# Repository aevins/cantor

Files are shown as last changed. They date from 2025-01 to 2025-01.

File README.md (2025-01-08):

<!-- markdownlint-disable MD000 -->




# Cantor Keyboard

(Forked by [aevins](https://github.com/aevins) - see [upstream](https://github.com/diepala/cantor) for original by [diepala](https://github.com/diepala))

The Cantor keyboard is a 42 key diodeless split keyboard, designed with simplicity in mind. It is inspired on the popular [corne](https://github.com/foostan/crkbd), [ferris](https://github.com/pierrechevalier83/ferris) and [sweep](https://github.com/davidphilipbarr/Sweep) keyboards, aiming to provide a more ergonomic (stronger column stagger) corne-like layout with a simple, easy to assemble and cheap design.

Cantor Keyboard

There are two versions of the Cantor:

The **Cantor Classic** uses choc switches with choc spacing. Therefore, only MBK keycaps can be used.

The **Cantor MX** uses either choc V1, choc V2, or MX switches with the slightly larger MX spacing. Keycaps for MX stems can be used. (OEM/SA/XDM/Cherry, etc.) 

Cantor Keyboard

### Why diodeless?

A diodeless design reduces the keyboard assembly time, as the amount of components to solder is significantly reduced.
Moreover, soldering diodes can cause trouble during the keyboard build. Diodes need to be placed in the correct direction, if not, the keys won't work well!
Eliminating diodes will prevent many errors during the assembly process.

## Disclaimers

All the designs and files are provided "AS IS" without any warranty or support.

## Design philosophy

The Cantor is designed with the following goals:

- Comfort
- Powerful
- Low cost
- Simplicity
- Ease of build
- USB-C
- No diodes

The PCB is reversible to reduce manufacturing costs.

## Getting started

Would you like to build this keyboard? Then continue reading!

You can also buy a kit to build the Cantor keyboard from one of the **honorable sponsors**:



<br><br><br><br>
  
### Bill of Materials

To build the keyboard, you will need the following materials:
#### Cantor Classic:
- 2x PCB boards (both are equal since they are reversible)
- 2x STM32F401CC blackpill microcontrollers (they are cheap on aliexpress)
- Pins and sockets for the microcontrollers (blackpill needs 20 pin stripes)
- 42 Choc v1 switches
- 42 MBK keycaps
- Some little rubber feet/bumpers (recommended 6 mm of diameter)
- 2x TRRS jacks (PJ-320A)
- 1x TRRS cable
- 1x USB cable compatible with your computer and the blackpill

#### Cantor MX
- Same as the classic, but switches can be choc v1, choc v2, MX 5 pin, or MX 3pin, and the compatible keycaps for chosen switches. MX 5 pin are preferable to 3 pin because they have more points of contact with the PCB.

- Cantor MX has slots for optional 'Tenting pucks'. They can be [purchased](https://splitkb.com/products/tenting-puck) or [3d printed](https://www.printables.com/model/235433-tenting-puck-for-keyboard-tripod-mount).

### Order the PCB

Download the gerber file from releases, and submit it to your favorite PCB manufacturer. The keyboard designs have been tested with JLCPCB. More details on the ordering process can be found in the [PCB Ordering Guide](doc/pcb_ordering_guide.md).

Note: if you don't want a random tracking number to be printed in the PCB, make sure to select the option 'Remove Order Number' in JLCPCB.

### How to Build

To build the keyboard, you'll also need a soldering iron and some tin. Follow the [build guide](doc/build_guide.md).

### Firmware

The Cantor keyboard uses the QMK firmware, which already supports this keyboard.

To flash the firmware to the microcontroller connect the blackpill to your computer and set it to bootloader mode. To do this the first time:

1. Press and hold the BOOT0 button.
2. Press and release the NRST button.
3. Release the BOOT0 button.

The following times you want to flash the keyboard, it is much simpler thanks to bootmagic. Hold the top left key of the keyboard and plug the microcontroller. If flashing the right part, hold the top right key.

## Feedback

If you have built this keyboard, please fill [this form](https://forms.gle/nfJCsei5hyHbjaHn9) to provide feedback. This will help to improve the keyboard design in future revisions.

Also, you can open an issue reporting any problem or feature request.

> [!NOTE]
> Please see [original](https://github.com/diepala/cantor) for issues - this fork is for my personal development. I will try to address questions/issues if you have them which **specifically** relate to this fork.

## Support

The development of a keyboard takes time and money. If you like this keyboard a want to support the original creator for the work and to develop future revisions of the keyboard, consider donating:

PayPal: 
GitHub: [Here](https://github.com/sponsors/diepala)

### Honorable sponsors

Thank you very much to everyone contributing and/or sponsoring this project. Special thanks to the honorable sponsors:




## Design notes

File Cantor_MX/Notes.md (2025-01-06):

# Notes

## Purchased Items

### Amazon

#### Keycaps

Keycaps

- [Guffercty kred XDA Profile Keycaps 125 Retro PBT Key Cap Cover Set Dye Sublimation ANSI US Layout for Cherry Mx Switch Mechanical Keyboard (XDA/Ember)](https://www.amazon.com/gp/product/B09HX228WX/ref=ppx_yo_dt_b_asin_title_o00_s01?ie=UTF8&psc=1)

#### Controller

Controller

- [DORHEA 3Pcs STM32F401 Development Board V3.0 STM32F401CCU6 STM32F4 Learning Board 84Mhz Freq 64KB RAM 256KB ROM for Programming](https://www.amazon.com/gp/product/B09MLHYF89/ref=ppx_yo_dt_b_asin_title_o00_s00?ie=UTF8&psc=1)

#### TRRS Jacks

Jacks

- [uxcell 3.5 mm Audio Jack Connector PCB Mount Female Socket 4 Pin PJ-320A 20pcs](https://www.amazon.com/gp/product/B07KY862P6/ref=ppx_yo_dt_b_asin_title_o00_s00?ie=UTF8&psc=1)

#### Cables

Cable - USB-C

- [USB C to USB C Cable, Type C 60W Fast Charging Nylon Braided Cable [5FT, 2 Pack] for iPhone 16 15 Pro Plus Pro Max, Samsung Galaxy S24/S23, MacBook Pro, iPad Pro Air Mini USBC Charger Cord [Grey]](https://www.amazon.com/gp/product/B0DC5HQGSQ/ref=ppx_yo_dt_b_asin_title_o00_s00?ie=UTF8&psc=1)

Cable - TRRS

- [Kework 12 inch 2.5mm TRRS Audio Cable, 90 Degree Angle 2.5mm Male Jack to 90 Degree Angle 2.5mm Male Jack AUX Audio Cable, Gold Plated Pure Copper, 2 Pack](https://www.amazon.com/gp/product/B0CM5Q2PP8/ref=ppx_yo_dt_b_asin_title_o00_s02?ie=UTF8&psc=1)

#### Solder

Solder

- [MAIYUM 63-37 Tin Lead Rosin core solder wire for electrical soldering (0.6mm 100g)](https://www.amazon.com/gp/product/B076QD1W9X/ref=ppx_yo_dt_b_asin_title_o00_s02?ie=UTF8&psc=1)

### JLCPCB

Order [W202501042351396](https://jlcpcb.com/user-center/orderDetails/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)

### AliExpress

None - though keycaps, blackpill microcontroller, and Outemu switches are common and cheap here.

## Firmware

## Extras

### Case

Case

This case was [designed by JellyTitan on Printables](https://www.printables.com/model/707238-cantor-mx-case) and seems a good fit for this board.

## Ideas

- Make it wireless
- Convert TRRS to USB-C
- Use sockets for hotswappable controller
- Modify to accept MX Hotswaps
- Read [article](https://github.com/joric/nrfmicro/wiki/Sockets) on sockets

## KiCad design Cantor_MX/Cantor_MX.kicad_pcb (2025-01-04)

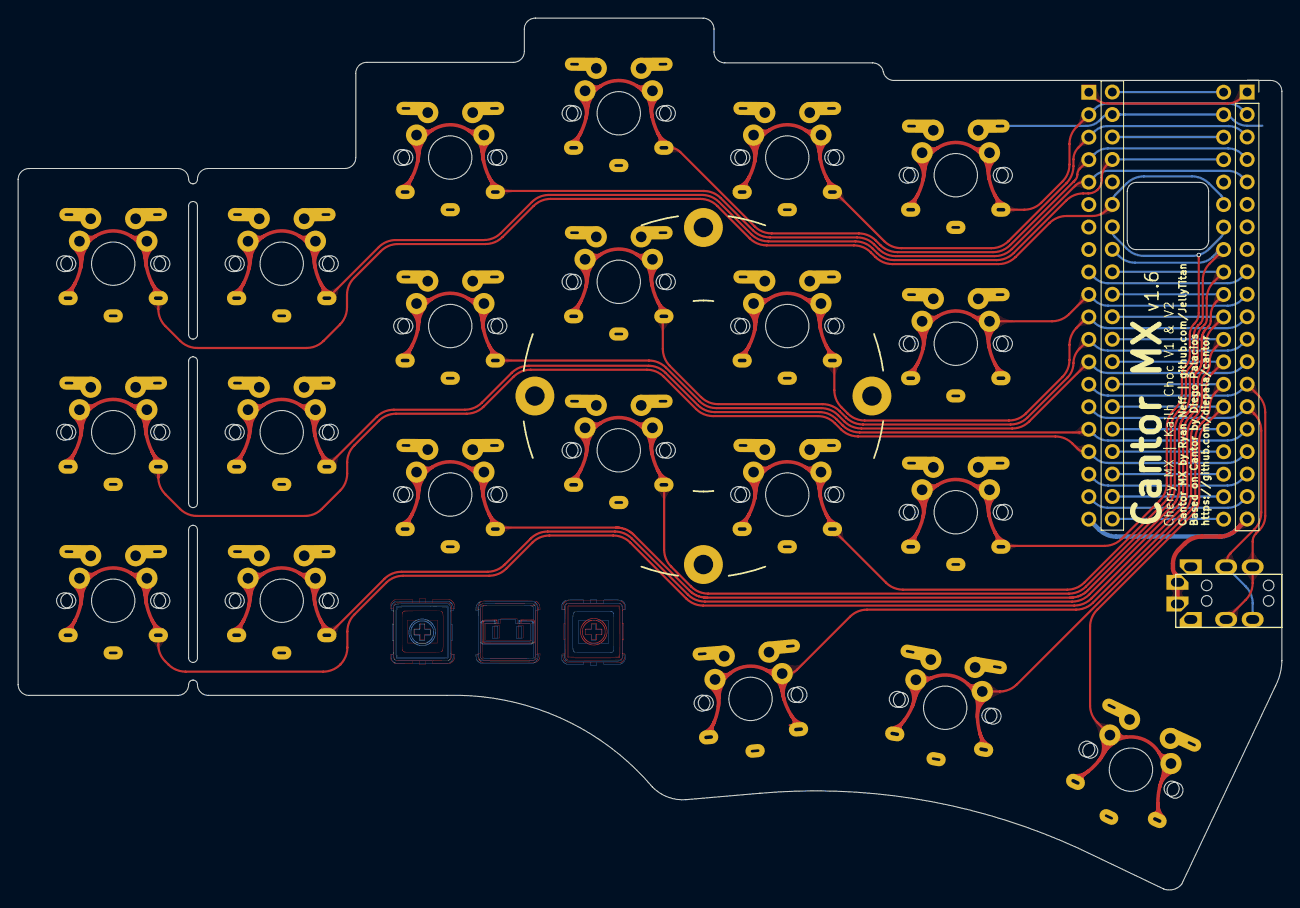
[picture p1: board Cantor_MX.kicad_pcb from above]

Board: 2 copper layers, 142.9 x 98.6 mm, 23 parts (0 on the bottom side), 25 nets.

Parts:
J1: TRRS; MJ-4PP-9_Cantor_MX_TX-RX_Crossover
K00, K01, K02, K03, K04, K05, K10, K11, K12, K13, K14, K15, K20, K21, K22, K23, K24, K25, K30, K31, K32: KEYSW; CherryMX_ChocV2_1u_DS
U1: YAAJ_WeAct_BlackPill_Part_Like; Cantor_DS_YAAJ_WeAct_BlackPill_2

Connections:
+3V3: J1.1 (SLEEVE), U1.20 (3V3), U1.38 (3V3)
/RX: J1.3 (RING1), U1.15 (PB7)
/TX: J1.4 (RING2), U1.14 (PB6)
/k00: K00.1, U1.35 (PB1)
/k01: K01.1, U1.37 (PB10)
/k02: K02.1, U1.5 (PA8)
/k03: K03.1, U1.4 (PB15)
/k04: K04.1, U1.3 (PB14)
/k05: K05.1, U1.2 (PB13)
/k10: K10.1, U1.17 (PB9)
/k11: K11.1, U1.16 (PB8)
/k12: K12.1, U1.13 (PB5)
/k13: K13.1, U1.12 (PB4)
/k14: K14.1, U1.11 (PB3)
/k15: K15.1, U1.10 (PA15)
/k20: K20.1, U1.29 (PA3)
/k21: K21.1, U1.30 (PA4)
/k22: K22.1, U1.31 (PA5)
/k23: K23.1, U1.32 (PA6)
/k24: K24.1, U1.33 (PA7)
/k25: K25.1, U1.34 (PB0)
/k30: K30.1, U1.28 (PA2)
/k31: K31.1, U1.27 (PA1)
/k32: K32.1, U1.26 (PA0)
GND: J1.2 (TIP), K00.2, K01.2, K02.2, K03.2, K04.2, K05.2, K10.2, K11.2, K12.2, K13.2, K14.2, K15.2, K20.2, K21.2, K22.2, K23.2, K24.2, K25.2, K30.2, K31.2, K32.2, U1.19 (GND), U1.39 (GND)

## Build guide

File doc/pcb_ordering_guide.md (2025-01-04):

<!-- markdownlint-disable MD033 -->
# PCB Ordering Guide

How to order this board from a PCB vendor - helpful info if it's your first time ordering a PCB.

Most PCB vendors have a similar ordering process. I use [JLCPCB](https://jlcpcb.com/) because they are usually the most cost effective. I've had good luck with [Elecrow](https://www.elecrow.com/) too. [You can find PCB price comparison tools online.](https://pcbshopper.com/) When comparing pricing, the board dimensions are  143mm x 93mm. (Usually anything under 100x100mm is really cheap - so be sure to use the 143x93 dimensions when pricing).

Usually the minimum quantity to order is 5 boards.

The production files are known as "gerbers", and they are usually uploaded as a `.zip` file. (It's essentially a collection of files for each layer of the board, like holes, graphics, traces etc.)

In this repo, the gerber file for the Cantor classic and the Cantor MX can be found under [releases](https://github.com/diepala/cantor/releases).

The homepage of JLCPCB has a drag & drop upload. Drag the gerber `.zip` and drop it on the "add gerber file" box.
JLCPCB Home

While the file is uploading, it will take you to an options screen. Once the board size is detected<sup>1</sup>, the price<sup>3</sup> will update accordingly.
Changing the pcb color<sup>2</sup> may impact production time and price.
Shipping estimates<sup>4</sup> can vary widely, so be sure to check those. (You'll see these options again during checkout).
JLCPCB Home
It's worth noting, the default pcb surface finish contains Lead. For boards in cases, this is usually not a problem. If you're going to rock a naked board, consider going with "lead free" for a few bucks more.

JLCPCB Home
The remainder of the checkout process is standard ecommerce stuff. After you pay for your order, it will be reviewed before going into production. They will let you know if the file has any issues.
